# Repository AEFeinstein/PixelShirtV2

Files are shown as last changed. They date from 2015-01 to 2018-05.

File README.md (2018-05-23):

View this project on [CADLAB.io](https://cadlab.io/project/1073). 

# PixelShirtV2
PixelShirtV2 is an Arduino based collection of video games running on a matrix of WS2812b LEDs and controlled by [ATmega328p based wireless controllers](https://github.com/AEFeinstein/WirelessController). It's meant to be mounted on a shirt, but can be put anywhere.

## The Firmware

The firmware can be compiled two different ways. If one uses the makefile, it compiles as a Linux terminal application that uses the keyboard as input and draws to the terminal using ncurses. This is used for debugging. If one loads it into the Arduino IDE, it compiles as an Arduino executable that uses NRF24L01+ controllers as input and draws to a matrix of WS2812B LEDs.

Each game is a subclass of ArduinoGame. This allows the main function to keep an array of ArduinoGame pointers, and swap between them at runtime. The virtual functions each game must implement are:
* `void UpdatePhysics(void)` - This is called on an IRQ_HZ clock, currently 32Hz. Game state should be updated here.
* `void ProcessInput(int32_t p1, int32_t p2)` - This is called every time there is new player input, which may be more or less often than 32Hz. Each 32 bit parameter contains bitpacked analog joystick and digital button state.
* `void ResetGame(uint8_t isInit, uint8_t whoWon)` - This is called during initialization (noted by isInit). It should reset the game to a known state. It is usually called at the end of each round of a game with which player won (noted by whoWon), though that is game-specific.

The firmware uses the [Adafruit Neopixel Library](https://github.com/adafruit/Adafruit_NeoPixel) to drive the WS2812B LEDs.

The firmware uses the [nrf24L01+ Radio Library](https://github.com/kehribar/nrf24L01_plus) to talk to the controllers.

The current game roster is
* Pong - Move your paddle and don't let the ball get past you.
* Team Tetris - Like regular Tetris, but one player slides the piece while the other rotates. Each time a new piece spawns, the player roles swap.
* Lightcycle - Drive around, leaving a trail, and don't crash into either your or your opponent's trail. The field wraps around top-bottom and left-right.
* PixelFighter - A simple 2D fighter. Attack or block high or low and knock off your opponent's life bar,
* Space Invader - Two players shoot upwards as invaders slide to the left, drop, and reverse direction. The more invaders shot, the faster they go.

## The Hardware

The hardware consists of two parts, detailed below. 

### The Console

The first part is the pocket-sized console, which has the Arduino Micro, NRF24L01+ radio, two RJ45 jacks which break out Arduino pins, and two USB connectors which draw power from an external battery. There are two USB connectors because I used an external battery with two USB connectors which could each source 1A. Not that I ever turned the display on to max brightness, but 2A never hurt anyone...

Screenshots of the PCB layout, the top view is on the left and the bottom view is on the right:
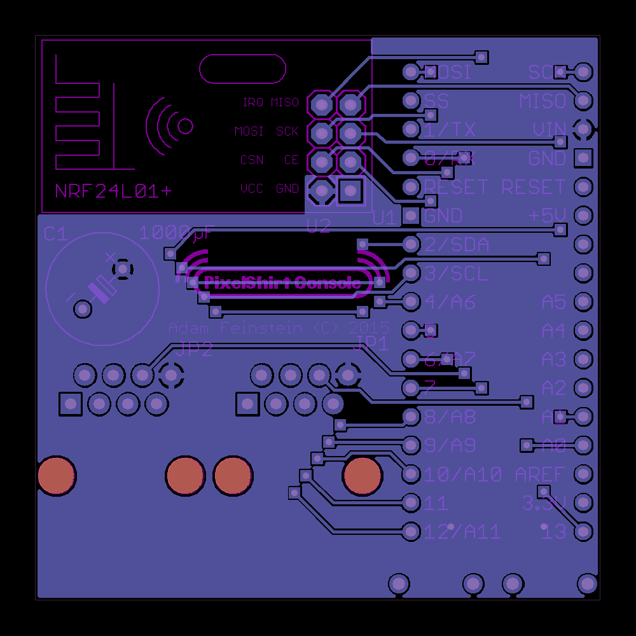
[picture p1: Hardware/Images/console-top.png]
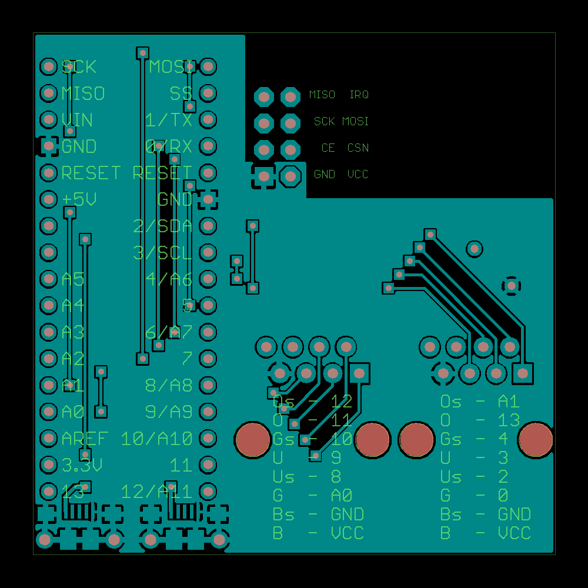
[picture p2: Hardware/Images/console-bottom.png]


This is what it looks like all soldered together:
<br>

### The Display

The second part is the chest-sized display, which has 256 WS2812B LEDs and an RJ45 connector to connect to the console for power and data. This is a one layer board, though it uses four 0-ohm resistors to jump over traces.

Screenshot of the PCB layout:
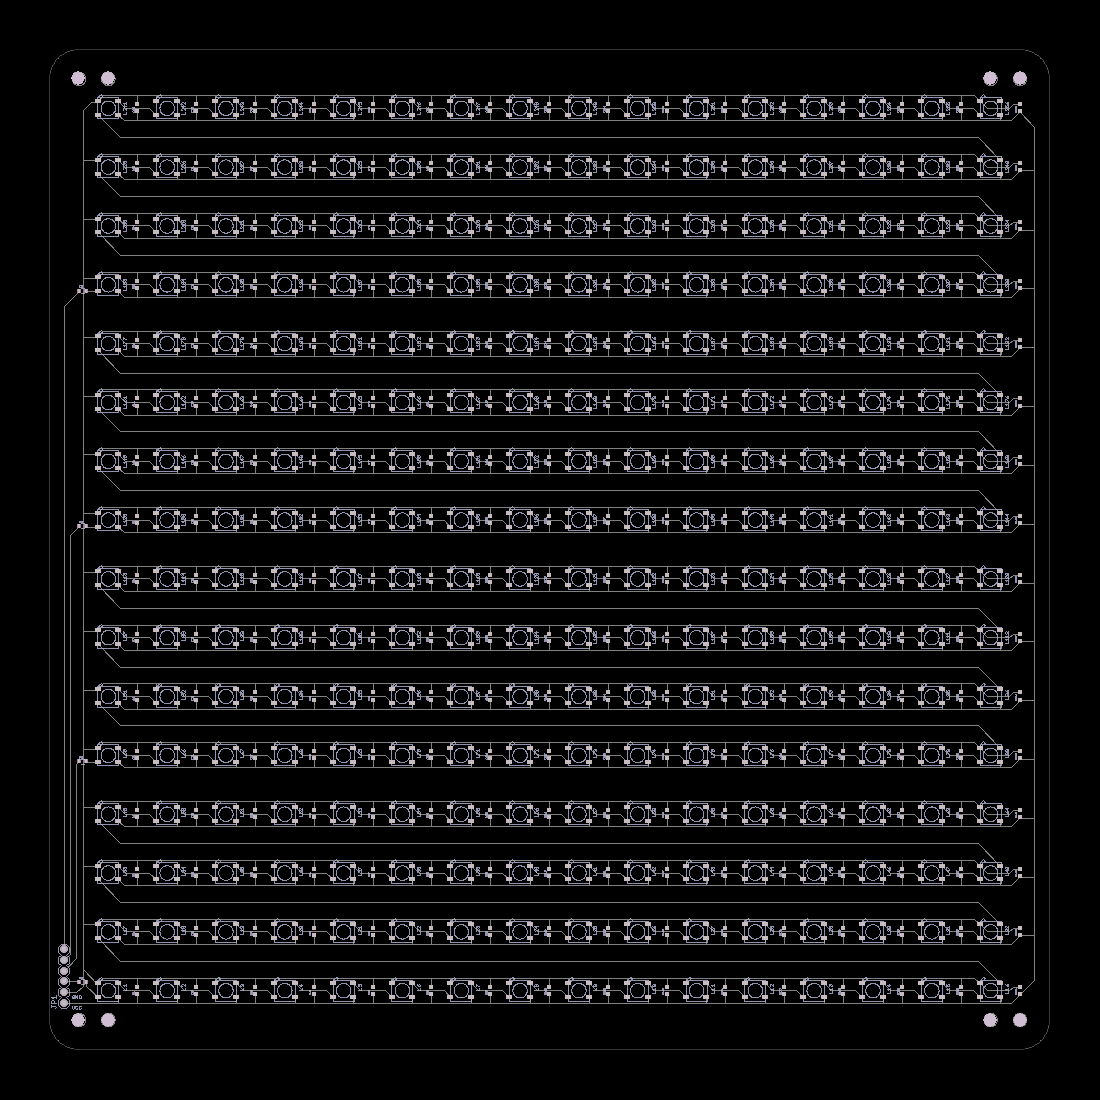
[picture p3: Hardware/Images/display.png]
<br>

This is what it looks like all soldered together. Not pictured, RJ45 connector at the end of the cable:
<br>

## The Final Product
Here's me at Magfest 14 wearing the display mounted underneath a shirt and holding two controllers. The PixelShirtV2 is playing the PixelFighter game.
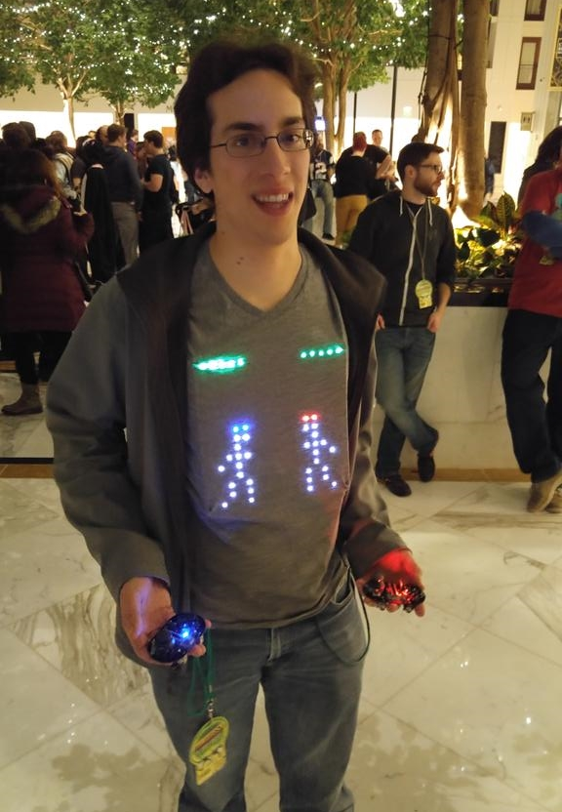
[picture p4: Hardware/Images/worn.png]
<br>

# Earlier Versions

## Version 1
The first version of the PixelShirt used blue LEDs poked through a t-shirt. The cathodes were soldered together in rows, a layer of insulating fabric was layered, then the anodes were soldered in columns. The 32 rows and columns were controlled by four daisy chained 8-bit shift registers and the display would refresh one row at a time, kind of like a CRT TV.
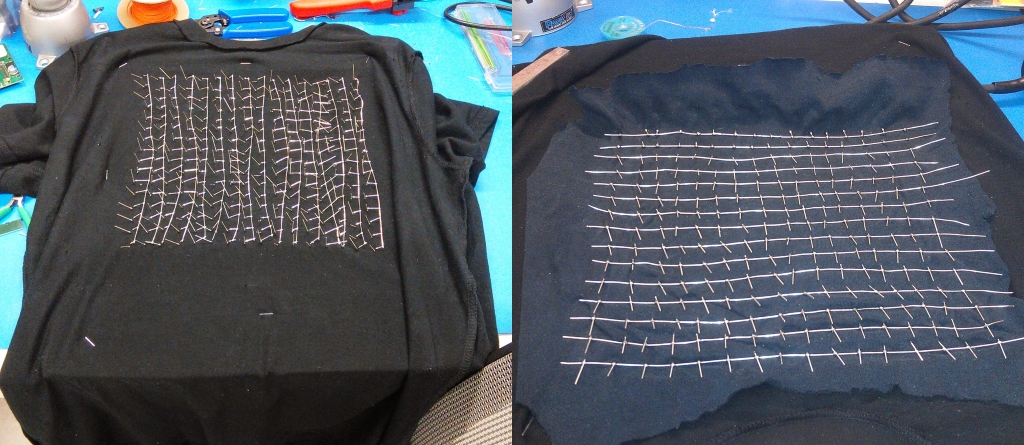
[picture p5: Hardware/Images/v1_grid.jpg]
<br>

The upside to this design was that the LED grid was flexible and comfortable. The downside was that it wasn't mechanically strong (a few solder joints broke), the grid wasn't very regular (I'm not great with fabrics), and it just generally didn't look good. The controllers are [SparkFun Joystick Shield Kits](https://www.sparkfun.com/products/9760). 
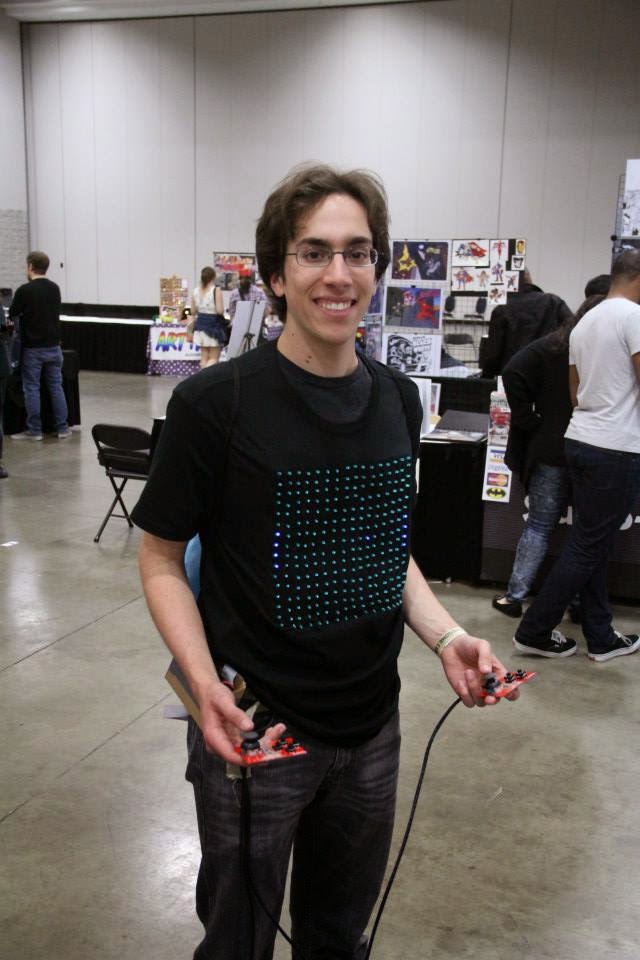
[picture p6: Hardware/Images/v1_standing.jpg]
<br>

But people seemed to get a kick out of it, so I iterated on the design. I wore it first at Magfest 12, but I think this picture is from AwesomeCon. At the time it only had Pong, Lightcycle, and Tetris.
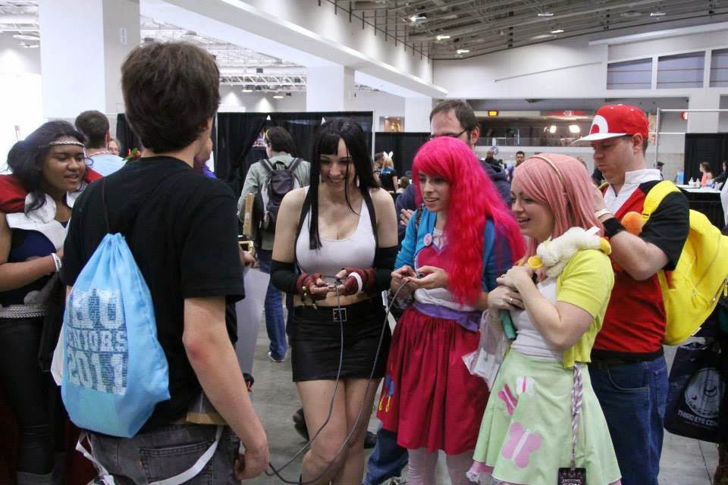
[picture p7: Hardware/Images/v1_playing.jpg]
<br>

## Version 2.0
The next year I swapped out the display for the giant PCB with RGB LEDs. Pros: colors! mechanical strength! no undershirt required! Cons: less flexible. I kept the same Sparkfun controllers. I wore this one at Magfest 13. With the advent of color, I added Space Invader.
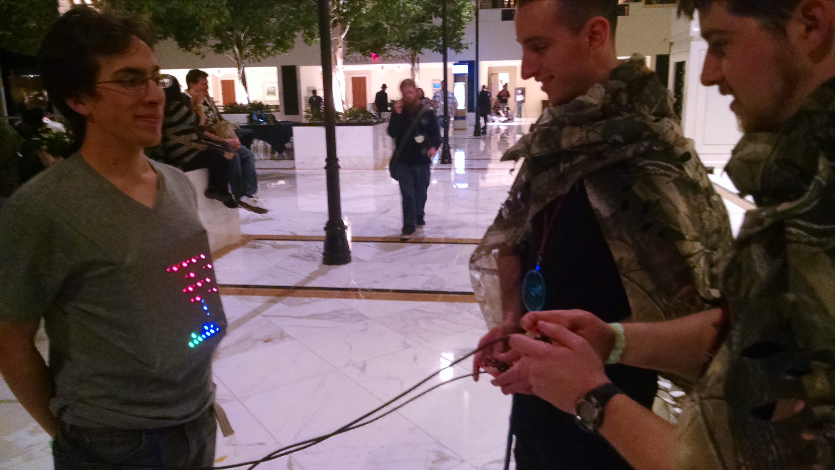
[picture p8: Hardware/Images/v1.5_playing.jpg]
<br>

## Version 2.1
For Magfest 14, I got over my fear of non-tethered controllers and made [wireless ones](https://github.com/AEFeinstein/WirelessController), which are mentioned above. They worked great and I didn't lose either one, but I did accidentally short their batteries a little when carelessly throwing them in a pocket. They got warm, but no harm no foul.

## Version 2.2
Magfest 15 only had software updates. I added the Fighter and Super Square games. There were no changes for Magfest 16, and I ended up not wearing it at all :(

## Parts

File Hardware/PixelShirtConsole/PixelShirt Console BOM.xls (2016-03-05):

Cost | Quantity | Description | PCB Reference | Part Number | Link
$24.95 | 1 | Arduino Micro | U1 |  | http://store-usa.arduino.cc/products/a000053
$2.90 | 1 | NRF24L01+MODULE | U2 | 1597-1352-ND | https://www.digikey.com/product-detail/en/seeed-technology-ltd/113990011/1597-1352-ND/5488251
$0.57 | 2 | CONN MOD JACK 8P8C R/A UNSHLD | JP1, JP2 | 609-1046-ND | https://www.digikey.com/product-detail/en/amphenol-fci/54602-908LF/609-1046-ND/1001360
$0.46 | 2 | USB micro B Receptacle, Surface Mount, Right Angle, Horizontal | JP3, JP4 | 609-4616-1-ND | https://www.digikey.com/product-detail/en/amphenol-fci/10118193-0001LF/609-4616-1-ND/2785380
$0.40 | 1 | CAP ALUM 1000UF 20% 10V RADIAL | C1 | 493-10963-1-ND | https://www.digikey.com/product-detail/en/nichicon/UFW1A102MPD1TD/493-10963-1-ND/4317887
$2.00 | 1 | PixelShirtV2 Console PCB |  |  | https://github.com/AEFeinstein/PixelShirtV2/tree/master/Hardware/PixelShirtConsole
$30.31

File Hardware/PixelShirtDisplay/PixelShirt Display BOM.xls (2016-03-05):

Cost | Quantity | Description | PCB Reference | Part Number | Link
$0.01 | 256 | CAP CER 0.1UF 16V X7R 0603 | C1-C256 | 490-1532-1-ND | https://www.digikey.com/product-detail/en/murata-electronics-north-america/GRM188R71C104KA01D/490-1532-1-ND/587771
$4.05 | 26 | LED RGB WS2812B W/DVR 4SMD 10PK | L1-L256 | 1528-1104-ND | https://www.digikey.com/product-detail/en/adafruit-industries-llc/1655/1528-1104-ND/5154679
$0.09 | 4 | RES SMD 0.0OHM JUMPER 1/10W 0603 | R2-R5 | 311-0.0HRCT-ND | https://www.digikey.com/product-detail/en/yageo/RC0603FR-070RL/311-0.0HRCT-ND/4340584
$0.26 | 1 | 2.54MM PITCH 06 POS SIL HORIZ | JP1 | 952-2372-ND | https://www.digikey.com/product-detail/en/harwin-inc/M20-9710646/952-2372-ND/3724334
$2.19 | 1 | CABLE RJ45 CAT5E W/BOOT 3' BLK |  | AE10480-ND | https://www.digikey.com/product-detail/en/assmann-wsw-components/DK-1511-003%2FBL/AE10480-ND/2268272
$10.00 | 1 | PixelShirt Display PCB |  |  | https://github.com/AEFeinstein/PixelShirtV2/tree/master/Hardware/PixelShirtDisplay
$109.91
 |  | Note: It's cheaper to get the 256 WS2812Bs on ebay

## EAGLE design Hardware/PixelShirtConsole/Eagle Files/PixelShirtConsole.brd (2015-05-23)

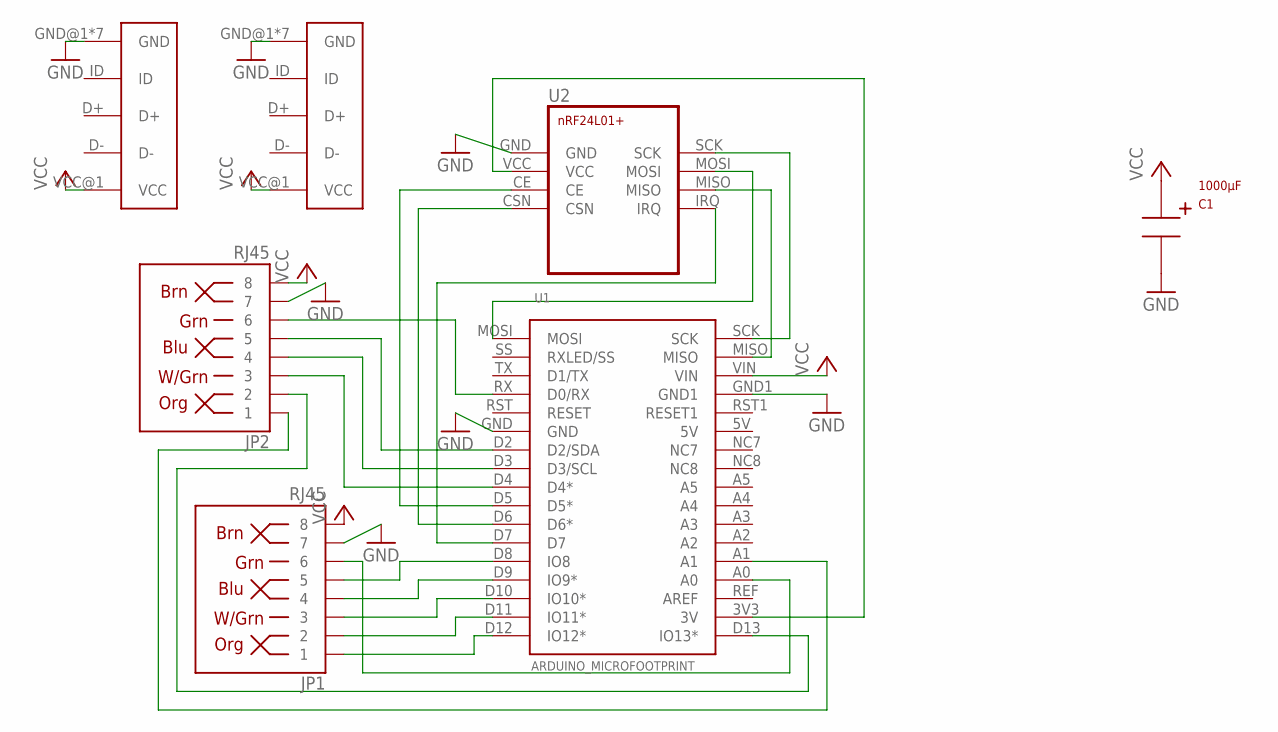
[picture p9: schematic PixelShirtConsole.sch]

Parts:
C1: 1000µF; CAP-CUSTOM
JP1, JP2: RJ45; RJ45-8
JP3, JP4: USB-MICRO-B
U1: ARDUINO_MICROFOOTPRINT; ARDUINO-MICRO
U2: NRF24L01+

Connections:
GND: C1.GND, JP1.7, JP2.7, JP3.GND@1 (GND), JP3.GND@2 (GND), JP3.GND@3 (GND), JP3.GND@5 (GND), JP3.GND@6 (GND), JP3.GND@7 (GND), JP3.GNF@4 (GND), JP4.GND@1 (GND), JP4.GND@2 (GND), JP4.GND@3 (GND), JP4.GND@5 (GND), JP4.GND@6 (GND), JP4.GND@7 (GND), JP4.GNF@4 (GND), U1.GND, U1.GND1, U2.GND
unnamed: U1.MISO, U2.MISO
unnamed: U1.SCK, U2.SCK
unnamed: U1.D6 (D6*), U2.CSN
unnamed: U1.D5 (D5*), U2.CE
unnamed: U1.MOSI, U2.MOSI
unnamed: U1.D7, U2.IRQ
unnamed: JP1.2, U1.D11 (IO11*)
unnamed: JP1.3, U1.D10 (IO10*)
unnamed: JP1.4, U1.D9 (IO9*)
unnamed: JP1.1, U1.D12 (IO12*)
unnamed: JP1.6, U1.A0
unnamed: JP1.5, U1.D8 (IO8)
unnamed: JP2.5, U1.D2 (D2/SDA)
unnamed: JP2.4, U1.D3 (D3/SCL)
unnamed: JP2.3, U1.D4 (D4*)
unnamed: JP2.6, U1.RX (D0/RX)
unnamed: JP2.1, U1.A1
unnamed: JP2.2, U1.D13 (IO13*)
unnamed: U1.3V3 (3V), U2.VCC
VCC: C1.VCC, JP1.8, JP2.8, JP3.VCC@1 (VCC), JP4.VCC@1 (VCC), U1.VIN

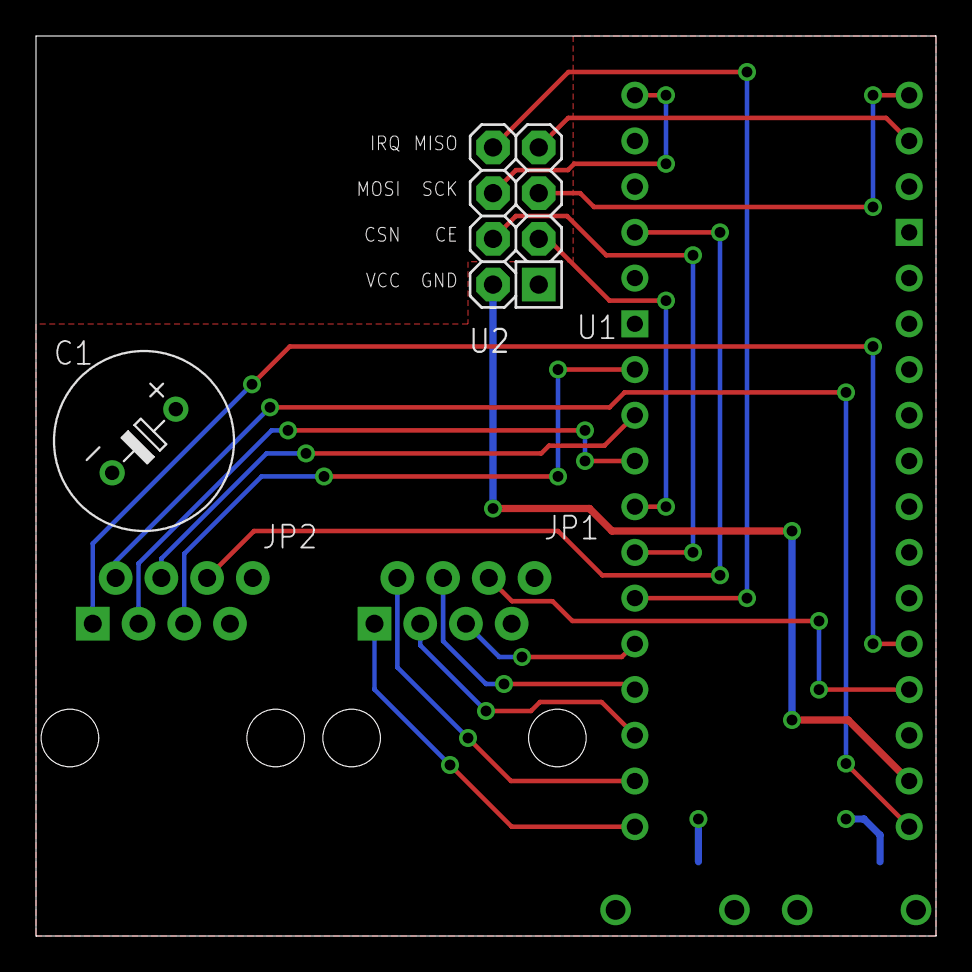
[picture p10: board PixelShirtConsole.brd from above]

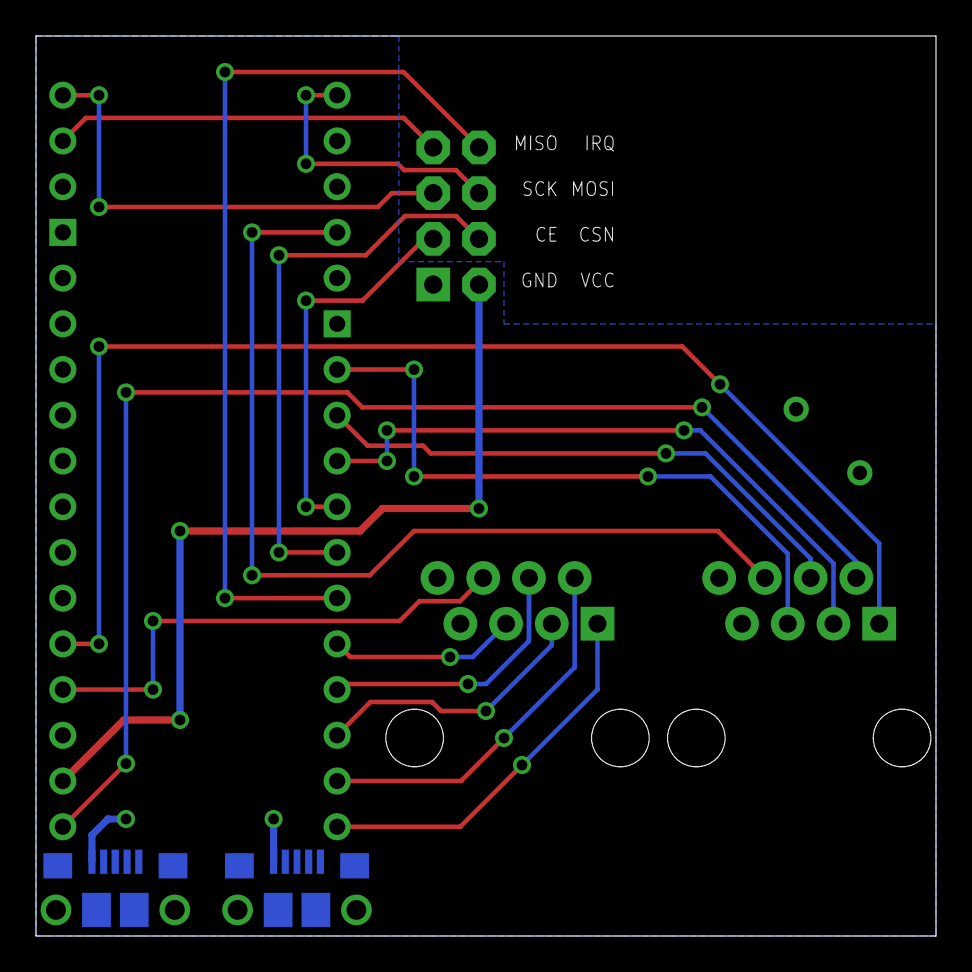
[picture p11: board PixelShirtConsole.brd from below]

Board: 2 copper layers, 50.0 x 50.0 mm, 7 parts (2 on the bottom side), 21 nets.

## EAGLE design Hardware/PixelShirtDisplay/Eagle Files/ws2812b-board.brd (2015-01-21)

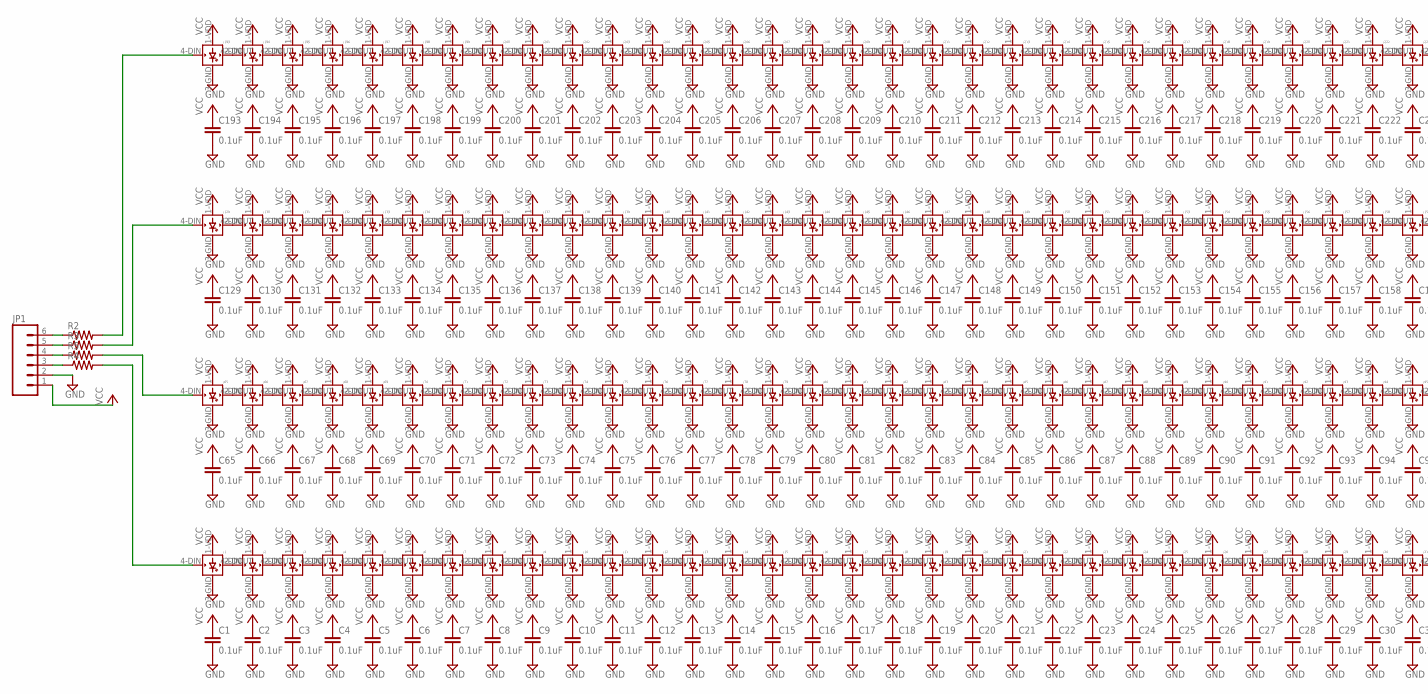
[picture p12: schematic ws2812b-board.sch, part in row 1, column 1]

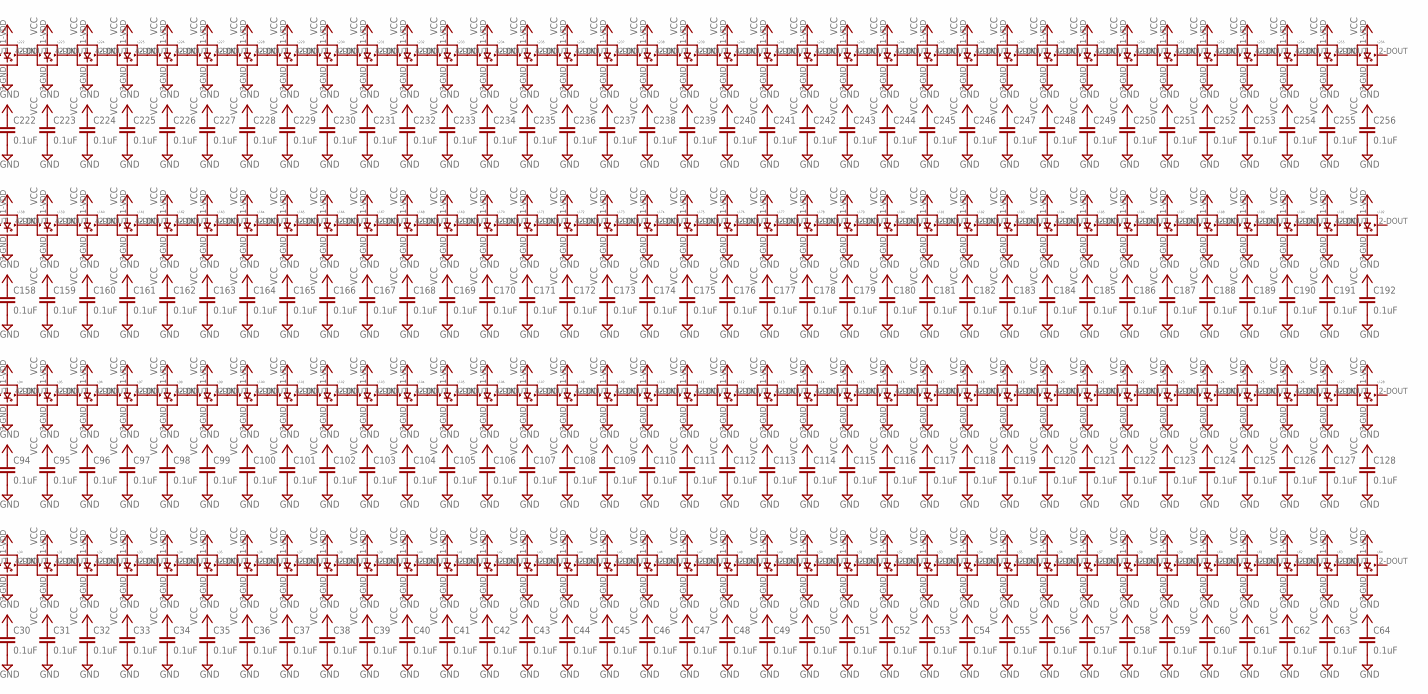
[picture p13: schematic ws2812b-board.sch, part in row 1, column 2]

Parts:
C1, C2, C3, C4, C5, C6, C7, C8, C9, C10, C11, C12, C13, C14, C15, C16, C17, C18, C19, C20, C21, C22, C23, C24, C25, C26, C27, C28, C29, C30, C31, C32, C33, C34, C35, C36, C37, C38, C39, C40, C41, C42, C43, C44, C45, C46, C47, C48, C49, C50, C51, C52, C53, C54, C55, C56, C57, C58, C59, C60, C61, C62, C63, C64, C65, C66, C67, C68, C69, C70, C71, C72, C73, C74, C75, C76, C77, C78, C79, C80, C81, C82, C83, C84, C85, C86, C87, C88, C89, C90, C91, C92, C93, C94, C95, C96, C97, C98, C99, C100, C101, C102, C103, C104, C105, C106, C107, C108, C109, C110, C111, C112, C113, C114, C115, C116, C117, C118, C119, C120, C121, C122, C123, C124, C125, C126, C127, C128, C129, C130, C131, C132, C133, C134, C135, C136, C137, C138, C139, C140, C141, C142, C143, C144, C145, C146, C147, C148, C149, C150, C151, C152, C153, C154, C155, C156, C157, C158, C159, C160, C161, C162, C163, C164, C165, C166, C167, C168, C169, C170, C171, C172, C173, C174, C175, C176, C177, C178, C179, C180, C181, C182, C183, C184, C185, C186, C187, C188, C189, C190, C191, C192, C193, C194, C195, C196, C197, C198, C199, C200, C201, C202, C203, C204, C205, C206, C207, C208, C209, C210, C211, C212, C213, C214, C215, C216, C217, C218, C219, C220, C221, C222, C223, C224, C225, C226, C227, C228, C229, C230, C231, C232, C233, C234, C235, C236, C237, C238, C239, C240, C241, C242, C243, C244, C245, C246, C247, C248, C249, C250, C251, C252, C253, C254, C255, C256: 0.1uF; 0603-CAP
JP1: M06SIP; 1X06
L1, L2, L3, L4, L5, L6, L7, L8, L9, L10, L11, L12, L13, L14, L15, L16, L17, L18, L19, L20, L21, L22, L23, L24, L25, L26, L27, L28, L29, L30, L31, L32, L33, L34, L35, L36, L37, L38, L39, L40, L41, L42, L43, L44, L45, L46, L47, L48, L49, L50, L51, L52, L53, L54, L55, L56, L57, L58, L59, L60, L61, L62, L63, L64, L65, L66, L67, L68, L69, L70, L71, L72, L73, L74, L75, L76, L77, L78, L79, L80, L81, L82, L83, L84, L85, L86, L87, L88, L89, L90, L91, L92, L93, L94, L95, L96, L97, L98, L99, L100, L101, L102, L103, L104, L105, L106, L107, L108, L109, L110, L111, L112, L113, L114, L115, L116, L117, L118, L119, L120, L121, L122, L123, L124, L125, L126, L127, L128, L129, L130, L131, L132, L133, L134, L135, L136, L137, L138, L139, L140, L141, L142, L143, L144, L145, L146, L147, L148, L149, L150, L151, L152, L153, L154, L155, L156, L157, L158, L159, L160, L161, L162, L163, L164, L165, L166, L167, L168, L169, L170, L171, L172, L173, L174, L175, L176, L177, L178, L179, L180, L181, L182, L183, L184, L185, L186, L187, L188, L189, L190, L191, L192, L193, L194, L195, L196, L197, L198, L199, L200, L201, L202, L203, L204, L205, L206, L207, L208, L209, L210, L211, L212, L213, L214, L215, L216, L217, L218, L219, L220, L221, L222, L223, L224, L225, L226, L227, L228, L229, L230, L231, L232, L233, L234, L235, L236, L237, L238, L239, L240, L241, L242, L243, L244, L245, L246, L247, L248, L249, L250, L251, L252, L253, L254, L255, L256: WS2812B
R2, R3, R4, R5: RESISTOR0805-RES; 0805

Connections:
GND: C1.2, C2.2, C3.2, C4.2, C5.2, C6.2, C7.2, C8.2, C9.2, C10.2, C11.2, C12.2, C13.2, C14.2, C15.2, C16.2, C17.2, C18.2, C19.2, C20.2, C21.2, C22.2, C23.2, C24.2, C25.2, C26.2, C27.2, C28.2, C29.2, C30.2, C31.2, C32.2, C33.2, C34.2, C35.2, C36.2, C37.2, C38.2, C39.2, C40.2, C41.2, C42.2, C43.2, C44.2, C45.2, C46.2, C47.2, C48.2, C49.2, C50.2, C51.2, C52.2, C53.2, C54.2, C55.2, C56.2, C57.2, C58.2, C59.2, C60.2, C61.2, C62.2, C63.2, C64.2, C65.2, C66.2, C67.2, C68.2, C69.2, C70.2, C71.2, C72.2, C73.2, C74.2, C75.2, C76.2, C77.2, C78.2, C79.2, C80.2, C81.2, C82.2, C83.2, C84.2, C85.2, C86.2, C87.2, C88.2, C89.2, C90.2, C91.2, C92.2, C93.2, C94.2, C95.2, C96.2, C97.2, C98.2, C99.2, C100.2, C101.2, C102.2, C103.2, C104.2, C105.2, C106.2, C107.2, C108.2, C109.2, C110.2, C111.2, C112.2, C113.2, C114.2, C115.2, C116.2, C117.2, C118.2, C119.2, C120.2, C121.2, C122.2, C123.2, C124.2, C125.2, C126.2, C127.2, C128.2, C129.2, C130.2, C131.2, C132.2, C133.2, C134.2, C135.2, C136.2, C137.2, C138.2, C139.2, C140.2, C141.2, C142.2, C143.2, C144.2, C145.2, C146.2, C147.2, C148.2, C149.2, C150.2, C151.2, C152.2, C153.2, C154.2, C155.2, C156.2, C157.2, C158.2, C159.2, C160.2, C161.2, C162.2, C163.2, C164.2, C165.2, C166.2, C167.2, C168.2, C169.2, C170.2, C171.2, C172.2, C173.2, C174.2, C175.2, C176.2, C177.2, C178.2, C179.2, C180.2, C181.2, C182.2, C183.2, C184.2, C185.2, C186.2, C187.2, C188.2, C189.2, C190.2, C191.2, C192.2, C193.2, C194.2, C195.2, C196.2, C197.2, C198.2, C199.2, C200.2, C201.2, C202.2, C203.2, C204.2, C205.2, C206.2, C207.2, C208.2, C209.2, C210.2, C211.2, C212.2, C213.2, C214.2, C215.2, C216.2, C217.2, C218.2, C219.2, C220.2, C221.2, C222.2, C223.2, C224.2, C225.2, C226.2, C227.2, C228.2, C229.2, C230.2, C231.2, C232.2, C233.2, C234.2, C235.2, C236.2, C237.2, C238.2, C239.2, C240.2, C241.2, C242.2, C243.2, C244.2, C245.2, C246.2, C247.2, C248.2, C249.2, C250.2, C251.2, C252.2, C253.2, C254.2, C255.2, C256.2, JP1.2, L1.3-GND (GND), L2.3-GND (GND), L3.3-GND (GND), L4.3-GND (GND), L5.3-GND (GND), L6.3-GND (GND), L7.3-GND (GND), L8.3-GND (GND), L9.3-GND (GND), L10.3-GND (GND), L11.3-GND (GND), L12.3-GND (GND), L13.3-GND (GND), L14.3-GND (GND), L15.3-GND (GND), L16.3-GND (GND), L17.3-GND (GND), L18.3-GND (GND), L19.3-GND (GND), L20.3-GND (GND), L21.3-GND (GND), L22.3-GND (GND), L23.3-GND (GND), L24.3-GND (GND), L25.3-GND (GND), L26.3-GND (GND), L27.3-GND (GND), L28.3-GND (GND), L29.3-GND (GND), L30.3-GND (GND), L31.3-GND (GND), L32.3-GND (GND), L33.3-GND (GND), L34.3-GND (GND), L35.3-GND (GND), L36.3-GND (GND), L37.3-GND (GND), L38.3-GND (GND), L39.3-GND (GND), L40.3-GND (GND), L41.3-GND (GND), L42.3-GND (GND), L43.3-GND (GND), L44.3-GND (GND), L45.3-GND (GND), L46.3-GND (GND), L47.3-GND (GND), L48.3-GND (GND), L49.3-GND (GND), L50.3-GND (GND), L51.3-GND (GND), L52.3-GND (GND), L53.3-GND (GND), L54.3-GND (GND), L55.3-GND (GND), L56.3-GND (GND), L57.3-GND (GND), L58.3-GND (GND), L59.3-GND (GND), L60.3-GND (GND), L61.3-GND (GND), L62.3-GND (GND), L63.3-GND (GND), L64.3-GND (GND), L65.3-GND (GND), L66.3-GND (GND), L67.3-GND (GND), L68.3-GND (GND), L69.3-GND (GND), L70.3-GND (GND), L71.3-GND (GND), L72.3-GND (GND), L73.3-GND (GND), L74.3-GND (GND), L75.3-GND (GND), L76.3-GND (GND), L77.3-GND (GND), L78.3-GND (GND), L79.3-GND (GND), L80.3-GND (GND), L81.3-GND (GND), L82.3-GND (GND), L83.3-GND (GND), L84.3-GND (GND), L85.3-GND (GND), L86.3-GND (GND), L87.3-GND (GND), L88.3-GND (GND), L89.3-GND (GND), L90.3-GND (GND), L91.3-GND (GND), L92.3-GND (GND), L93.3-GND (GND), L94.3-GND (GND), L95.3-GND (GND), L96.3-GND (GND), L97.3-GND (GND), L98.3-GND (GND), L99.3-GND (GND), L100.3-GND (GND), L101.3-GND (GND), L102.3-GND (GND), L103.3-GND (GND), L104.3-GND (GND), L105.3-GND (GND), L106.3-GND (GND), L107.3-GND (GND), L108.3-GND (GND), L109.3-GND (GND), L110.3-GND (GND), L111.3-GND (GND), L112.3-GND (GND), L113.3-GND (GND), L114.3-GND (GND), L115.3-GND (GND), L116.3-GND (GND), L117.3-GND (GND), L118.3-GND (GND), L119.3-GND (GND), L120.3-GND (GND), L121.3-GND (GND), L122.3-GND (GND), L123.3-GND (GND), L124.3-GND (GND), L125.3-GND (GND), L126.3-GND (GND), L127.3-GND (GND), L128.3-GND (GND), L129.3-GND (GND), L130.3-GND (GND), L131.3-GND (GND), L132.3-GND (GND), L133.3-GND (GND), L134.3-GND (GND), L135.3-GND (GND), L136.3-GND (GND), L137.3-GND (GND), L138.3-GND (GND), L139.3-GND (GND), L140.3-GND (GND), L141.3-GND (GND), L142.3-GND (GND), L143.3-GND (GND), L144.3-GND (GND), L145.3-GND (GND), L146.3-GND (GND), L147.3-GND (GND), L148.3-GND (GND), L149.3-GND (GND), L150.3-GND (GND), L151.3-GND (GND), L152.3-GND (GND), L153.3-GND (GND), L154.3-GND (GND), L155.3-GND (GND), L156.3-GND (GND), L157.3-GND (GND), L158.3-GND (GND), L159.3-GND (GND), L160.3-GND (GND), L161.3-GND (GND), L162.3-GND (GND), L163.3-GND (GND), L164.3-GND (GND), L165.3-GND (GND), L166.3-GND (GND), L167.3-GND (GND), L168.3-GND (GND), L169.3-GND (GND), L170.3-GND (GND), L171.3-GND (GND), L172.3-GND (GND), L173.3-GND (GND), L174.3-GND (GND), L175.3-GND (GND), L176.3-GND (GND), L177.3-GND (GND), L178.3-GND (GND), L179.3-GND (GND), L180.3-GND (GND), L181.3-GND (GND), L182.3-GND (GND), L183.3-GND (GND), L184.3-GND (GND), L185.3-GND (GND), L186.3-GND (GND), L187.3-GND (GND), L188.3-GND (GND), L189.3-GND (GND), L190.3-GND (GND), L191.3-GND (GND), L192.3-GND (GND), L193.3-GND (GND), L194.3-GND (GND), L195.3-GND (GND), L196.3-GND (GND), L197.3-GND (GND), L198.3-GND (GND), L199.3-GND (GND), L200.3-GND (GND), L201.3-GND (GND), L202.3-GND (GND), L203.3-GND (GND), L204.3-GND (GND), L205.3-GND (GND), L206.3-GND (GND), L207.3-GND (GND), L208.3-GND (GND), L209.3-GND (GND), L210.3-GND (GND), L211.3-GND (GND), L212.3-GND (GND), L213.3-GND (GND), L214.3-GND (GND), L215.3-GND (GND), L216.3-GND (GND), L217.3-GND (GND), L218.3-GND (GND), L219.3-GND (GND), L220.3-GND (GND), L221.3-GND (GND), L222.3-GND (GND), L223.3-GND (GND), L224.3-GND (GND), L225.3-GND (GND), L226.3-GND (GND), L227.3-GND (GND), L228.3-GND (GND), L229.3-GND (GND), L230.3-GND (GND), L231.3-GND (GND), L232.3-GND (GND), L233.3-GND (GND), L234.3-GND (GND), L235.3-GND (GND), L236.3-GND (GND), L237.3-GND (GND), L238.3-GND (GND), L239.3-GND (GND), L240.3-GND (GND), L241.3-GND (GND), L242.3-GND (GND), L243.3-GND (GND), L244.3-GND (GND), L245.3-GND (GND), L246.3-GND (GND), L247.3-GND (GND), L248.3-GND (GND), L249.3-GND (GND), L250.3-GND (GND), L251.3-GND (GND), L252.3-GND (GND), L253.3-GND (GND), L254.3-GND (GND), L255.3-GND (GND), L256.3-GND (GND)
unnamed: L1.2-DOUT (DOUT), L2.4-DIN (DIN)
unnamed: L2.2-DOUT (DOUT), L3.4-DIN (DIN)
unnamed: L3.2-DOUT (DOUT), L4.4-DIN (DIN)
unnamed: L4.2-DOUT (DOUT), L5.4-DIN (DIN)
unnamed: L5.2-DOUT (DOUT), L6.4-DIN (DIN)
unnamed: L6.2-DOUT (DOUT), L7.4-DIN (DIN)
unnamed: L7.2-DOUT (DOUT), L8.4-DIN (DIN)
unnamed: L8.2-DOUT (DOUT), L9.4-DIN (DIN)
unnamed: L9.2-DOUT (DOUT), L10.4-DIN (DIN)
unnamed: L10.2-DOUT (DOUT), L11.4-DIN (DIN)
unnamed: L11.2-DOUT (DOUT), L12.4-DIN (DIN)
unnamed: L12.2-DOUT (DOUT), L13.4-DIN (DIN)
unnamed: L13.2-DOUT (DOUT), L14.4-DIN (DIN)
unnamed: L14.2-DOUT (DOUT), L15.4-DIN (DIN)
unnamed: L15.2-DOUT (DOUT), L16.4-DIN (DIN)
unnamed: L16.2-DOUT (DOUT), L17.4-DIN (DIN)
unnamed: L17.2-DOUT (DOUT), L18.4-DIN (DIN)
unnamed: L18.2-DOUT (DOUT), L19.4-DIN (DIN)
unnamed: L19.2-DOUT (DOUT), L20.4-DIN (DIN)
unnamed: L20.2-DOUT (DOUT), L21.4-DIN (DIN)
unnamed: L21.2-DOUT (DOUT), L22.4-DIN (DIN)
unnamed: L22.2-DOUT (DOUT), L23.4-DIN (DIN)
unnamed: L23.2-DOUT (DOUT), L24.4-DIN (DIN)
unnamed: L24.2-DOUT (DOUT), L25.4-DIN (DIN)
unnamed: L25.2-DOUT (DOUT), L26.4-DIN (DIN)
unnamed: L26.2-DOUT (DOUT), L27.4-DIN (DIN)
unnamed: L27.2-DOUT (DOUT), L28.4-DIN (DIN)
unnamed: L28.2-DOUT (DOUT), L29.4-DIN (DIN)
unnamed: L29.2-DOUT (DOUT), L30.4-DIN (DIN)
unnamed: L30.2-DOUT (DOUT), L31.4-DIN (DIN)
unnamed: L31.2-DOUT (DOUT), L32.4-DIN (DIN)
unnamed: L32.2-DOUT (DOUT), L33.4-DIN (DIN)
unnamed: L33.2-DOUT (DOUT), L34.4-DIN (DIN)
unnamed: L34.2-DOUT (DOUT), L35.4-DIN (DIN)
unnamed: L35.2-DOUT (DOUT), L36.4-DIN (DIN)
unnamed: L36.2-DOUT (DOUT), L37.4-DIN (DIN)
unnamed: L37.2-DOUT (DOUT), L38.4-DIN (DIN)
unnamed: L38.2-DOUT (DOUT), L39.4-DIN (DIN)
unnamed: L39.2-DOUT (DOUT), L40.4-DIN (DIN)
unnamed: L40.2-DOUT (DOUT), L41.4-DIN (DIN)
unnamed: L41.2-DOUT (DOUT), L42.4-DIN (DIN)
unnamed: L42.2-DOUT (DOUT), L43.4-DIN (DIN)
unnamed: L43.2-DOUT (DOUT), L44.4-DIN (DIN)
unnamed: L44.2-DOUT (DOUT), L45.4-DIN (DIN)
unnamed: L45.2-DOUT (DOUT), L46.4-DIN (DIN)
unnamed: L46.2-DOUT (DOUT), L47.4-DIN (DIN)
unnamed: L47.2-DOUT (DOUT), L48.4-DIN (DIN)
unnamed: L48.2-DOUT (DOUT), L49.4-DIN (DIN)
unnamed: L49.2-DOUT (DOUT), L50.4-DIN (DIN)
unnamed: L50.2-DOUT (DOUT), L51.4-DIN (DIN)
unnamed: L51.2-DOUT (DOUT), L52.4-DIN (DIN)
unnamed: L52.2-DOUT (DOUT), L53.4-DIN (DIN)
unnamed: L53.2-DOUT (DOUT), L54.4-DIN (DIN)
unnamed: L54.2-DOUT (DOUT), L55.4-DIN (DIN)
unnamed: L55.2-DOUT (DOUT), L56.4-DIN (DIN)
unnamed: L56.2-DOUT (DOUT), L57.4-DIN (DIN)
unnamed: L57.2-DOUT (DOUT), L58.4-DIN (DIN)
unnamed: L58.2-DOUT (DOUT), L59.4-DIN (DIN)
unnamed: L59.2-DOUT (DOUT), L60.4-DIN (DIN)
unnamed: L60.2-DOUT (DOUT), L61.4-DIN (DIN)
unnamed: L61.2-DOUT (DOUT), L62.4-DIN (DIN)
unnamed: L62.2-DOUT (DOUT), L63.4-DIN (DIN)
unnamed: L63.2-DOUT (DOUT), L64.4-DIN (DIN)
unnamed: L65.2-DOUT (DOUT), L66.4-DIN (DIN)
unnamed: L66.2-DOUT (DOUT), L67.4-DIN (DIN)
unnamed: L67.2-DOUT (DOUT), L68.4-DIN (DIN)
unnamed: L68.2-DOUT (DOUT), L69.4-DIN (DIN)
unnamed: L69.2-DOUT (DOUT), L70.4-DIN (DIN)
unnamed: L70.2-DOUT (DOUT), L71.4-DIN (DIN)
unnamed: L71.2-DOUT (DOUT), L72.4-DIN (DIN)
unnamed: L72.2-DOUT (DOUT), L73.4-DIN (DIN)
unnamed: L73.2-DOUT (DOUT), L74.4-DIN (DIN)
unnamed: L74.2-DOUT (DOUT), L75.4-DIN (DIN)
unnamed: L75.2-DOUT (DOUT), L76.4-DIN (DIN)
unnamed: L76.2-DOUT (DOUT), L77.4-DIN (DIN)
unnamed: L77.2-DOUT (DOUT), L78.4-DIN (DIN)
unnamed: L78.2-DOUT (DOUT), L79.4-DIN (DIN)
unnamed: L79.2-DOUT (DOUT), L80.4-DIN (DIN)
unnamed: L80.2-DOUT (DOUT), L81.4-DIN (DIN)
unnamed: L81.2-DOUT (DOUT), L82.4-DIN (DIN)
unnamed: L82.2-DOUT (DOUT), L83.4-DIN (DIN)
unnamed: L83.2-DOUT (DOUT), L84.4-DIN (DIN)
unnamed: L84.2-DOUT (DOUT), L85.4-DIN (DIN)
unnamed: L85.2-DOUT (DOUT), L86.4-DIN (DIN)
unnamed: L86.2-DOUT (DOUT), L87.4-DIN (DIN)
unnamed: L87.2-DOUT (DOUT), L88.4-DIN (DIN)
unnamed: L88.2-DOUT (DOUT), L89.4-DIN (DIN)
unnamed: L89.2-DOUT (DOUT), L90.4-DIN (DIN)
unnamed: L90.2-DOUT (DOUT), L91.4-DIN (DIN)
unnamed: L91.2-DOUT (DOUT), L92.4-DIN (DIN)
unnamed: L92.2-DOUT (DOUT), L93.4-DIN (DIN)
unnamed: L93.2-DOUT (DOUT), L94.4-DIN (DIN)
unnamed: L94.2-DOUT (DOUT), L95.4-DIN (DIN)
unnamed: L95.2-DOUT (DOUT), L96.4-DIN (DIN)
unnamed: L96.2-DOUT (DOUT), L97.4-DIN (DIN)
unnamed: L97.2-DOUT (DOUT), L98.4-DIN (DIN)
unnamed: L98.2-DOUT (DOUT), L99.4-DIN (DIN)
unnamed: L99.2-DOUT (DOUT), L100.4-DIN (DIN)
unnamed: L100.2-DOUT (DOUT), L101.4-DIN (DIN)
unnamed: L101.2-DOUT (DOUT), L102.4-DIN (DIN)
unnamed: L102.2-DOUT (DOUT), L103.4-DIN (DIN)
unnamed: L103.2-DOUT (DOUT), L104.4-DIN (DIN)
unnamed: L104.2-DOUT (DOUT), L105.4-DIN (DIN)
unnamed: L105.2-DOUT (DOUT), L106.4-DIN (DIN)
unnamed: L106.2-DOUT (DOUT), L107.4-DIN (DIN)
unnamed: L107.2-DOUT (DOUT), L108.4-DIN (DIN)
unnamed: L108.2-DOUT (DOUT), L109.4-DIN (DIN)
unnamed: L109.2-DOUT (DOUT), L110.4-DIN (DIN)
unnamed: L110.2-DOUT (DOUT), L111.4-DIN (DIN)
unnamed: L111.2-DOUT (DOUT), L112.4-DIN (DIN)
unnamed: L112.2-DOUT (DOUT), L113.4-DIN (DIN)
unnamed: L113.2-DOUT (DOUT), L114.4-DIN (DIN)
unnamed: L114.2-DOUT (DOUT), L115.4-DIN (DIN)
unnamed: L115.2-DOUT (DOUT), L116.4-DIN (DIN)
unnamed: L116.2-DOUT (DOUT), L117.4-DIN (DIN)
unnamed: L117.2-DOUT (DOUT), L118.4-DIN (DIN)
unnamed: L118.2-DOUT (DOUT), L119.4-DIN (DIN)
unnamed: L119.2-DOUT (DOUT), L120.4-DIN (DIN)
unnamed: L120.2-DOUT (DOUT), L121.4-DIN (DIN)
unnamed: L121.2-DOUT (DOUT), L122.4-DIN (DIN)
unnamed: L122.2-DOUT (DOUT), L123.4-DIN (DIN)
unnamed: L123.2-DOUT (DOUT), L124.4-DIN (DIN)
unnamed: L124.2-DOUT (DOUT), L125.4-DIN (DIN)
unnamed: L125.2-DOUT (DOUT), L126.4-DIN (DIN)
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

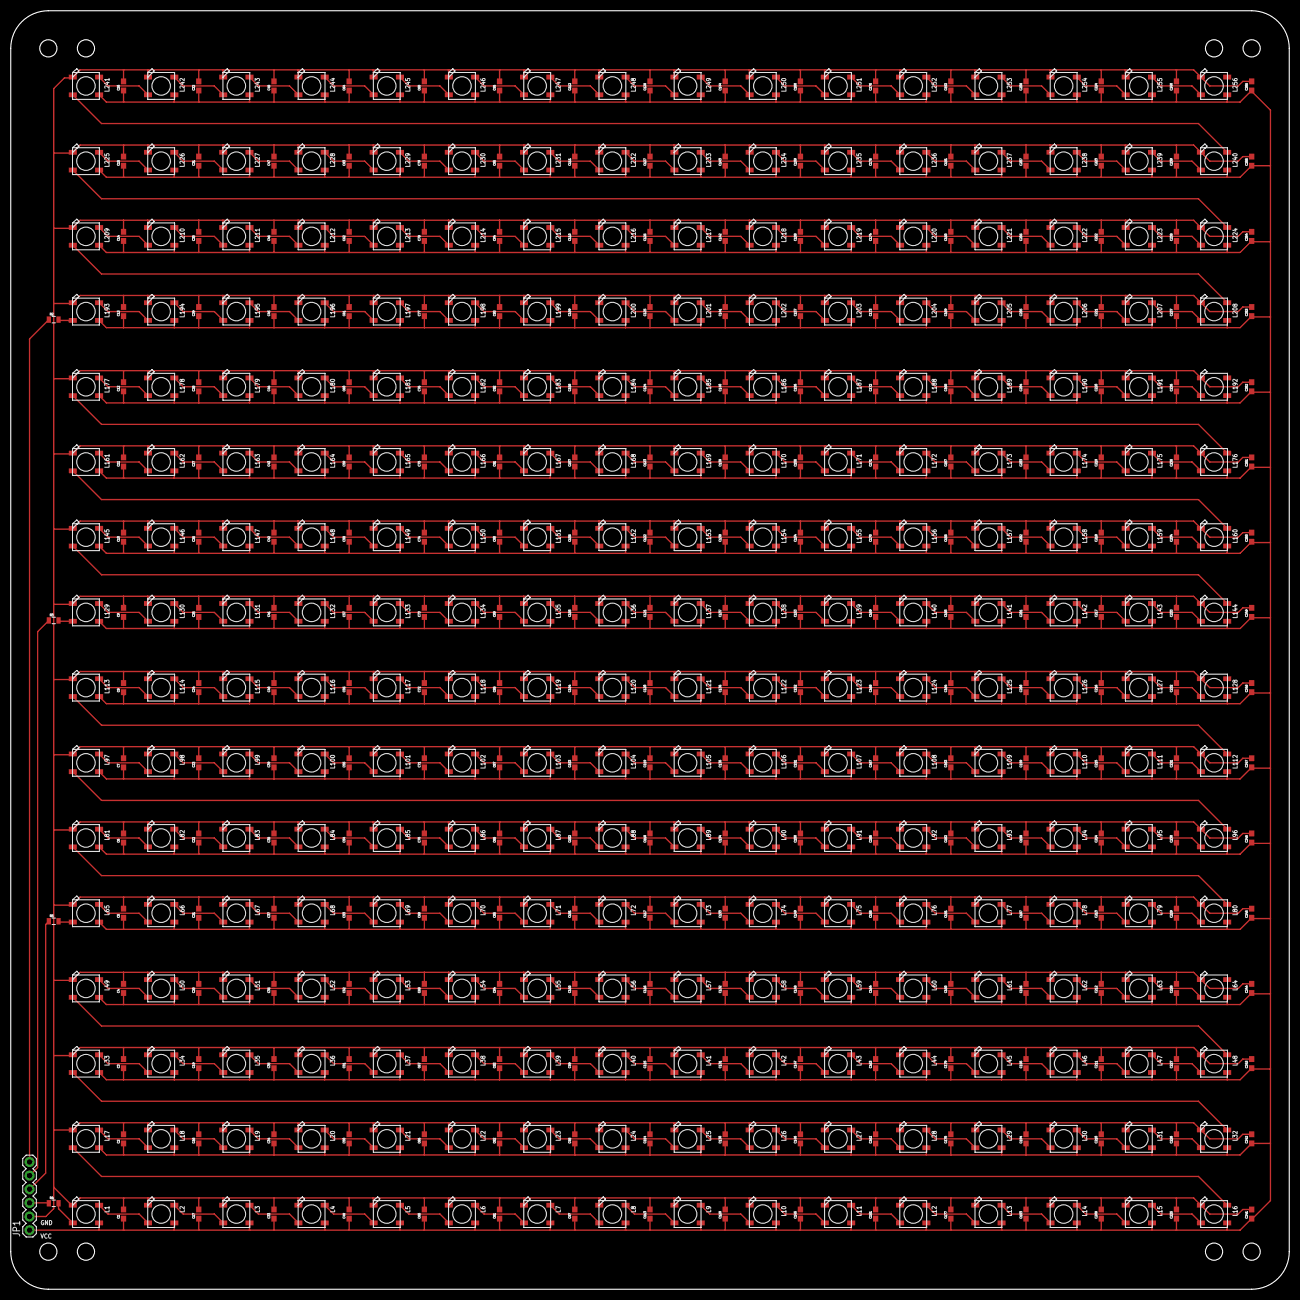
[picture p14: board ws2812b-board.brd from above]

Board: 2 copper layers, 238.0 x 238.0 mm, 517 parts (0 on the bottom side), 262 nets.

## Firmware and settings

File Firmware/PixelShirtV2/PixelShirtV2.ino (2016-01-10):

/* Copyright 2015 Adam Feinstein
 *
 * This file is part of PixelShirtV2.
 *
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
 * PixelShirtV2 is distributed in the hope that it will be useful,
 * but WITHOUT ANY WARRANTY; without even the implied warranty of
 * MERCHANTABILITY or FITNESS FOR A PARTICULAR PURPOSE.  See the
 * GNU General Public License for more details.
 * You should have received a copy of the GNU General Public License
 * along with PixelShirtV2.  If not, see <http://www.gnu.org/licenses/>.
 */

#include <stdint.h>
#include "ArduinoGame.h"

#include "Pong.h"
#include "Lightcycle.h"
#include "Tetris.h"
#include "SuperSquare.h"
#include "Shooter.h"
#include "PixelFighter.h"
#include "ScreenSaver.h"
#include "ScoreDisplay.h"

#include "PlatformSpecific.h"
#include "PixelShirtV2.h"

/* The different game IDs */
typedef enum {
  //  SUPER_SQUARE,
  PONG,
  LIGHTCYCLE,
  SHOOTER,
  TETRIS,
  FIGHTER,
  LAST_GAME
} gameType_t;

/* The current game's ID */
uint8_t gameMode;

/* A timer for game switching. It counts how long both "up" buttons are
 * pressed
 */
uint8_t gameSwitchTimer;

/* A pointer to the active game */
ArduinoGame* currentGame;

/* The collection of games */
//SuperSquare superSquare;
Pong pong;
Lightcycle lightcycle;
Shooter shooter;
Tetris tetris;
PixelFighterGame fighter;

/* To periodically call the main function in the loop */
uint32_t microsCnt = 0;
uint32_t microsLast = 0;

/* Variables to store controller state */
uint32_t p1controller;
uint32_t p2controller;

/* Prototypes */
void doEverything(void);

/**
 * The setup function. This is called once before loop() is called infinitely.
 * It sets up the hardware interfaces for driving LEDs and receiving controller
 * data. It also sets up the RNG, the initial game, and resets all state
 * variables.
 */
void setup(void)
{
  initializeHardware();

  /* Clear Variables */
  uint8_t x, y;
  for(x = 0; x < BOARD_SIZE; x++) {
    for(y = 0; y < BOARD_SIZE; y++) {
      SetPixel(x, y, EMPTY_COLOR);
    }
  }
  gameSwitchTimer = 0;

  /* Set the current game */
  gameMode = FIGHTER;
  currentGame = &fighter;
  currentGame->ResetGame(1,0);

  /* Initialize controller state */
  p1controller = 0;
  p2controller = 0;
  SET_X_AXIS(p1controller, 512);
  SET_Y_AXIS(p1controller, 512);
  SET_X_AXIS(p2controller, 512);
  SET_Y_AXIS(p2controller, 512);
}

/**
 * This function is called within an infinite loop. It calls doEverything() at
 * 32Hz and is always listening for controller input data. It also blinks
 * a heart-beat LED.
 */
void loop(void)
{
  uint32_t currentTime = getMicroseconds();

  /* Run the code at 32Hz (every 31250 microseconds)
   * Only add to the counter if it doesn't roll over
   */
  if(currentTime > microsLast) {
    microsCnt += (currentTime - microsLast);
  }
  if(microsCnt >= (1000000 / IRQ_HZ)) {
    microsCnt = 0;
    doEverything();
  }
  microsLast = currentTime;

  /* If there was new joystick data read, process it */
  if(readJoystickData(&p1controller, &p2controller)) {
    currentGame->ProcessInput(p1controller, p2controller);
    platformPostprocessInput(&p1controller, &p2controller);
  }
}

/**
 * This is called at 32Hz. It handles displaying the screen saver, switching
 * between game modes, sending controller input and update physics requests
 * to the active game, and actually pushing the pixel data out to the display.
 */
void doEverything(void)
{
  /* If both up buttons are held, maybe the game mode is being changed */
  if((GET_BUTTONS(p1controller) & UP) && (GET_BUTTONS(p2controller) & UP)) {
    gameSwitchTimer++;
  }
  else {
    gameSwitchTimer = 0;
  }

  /* If there is any input, exit the screen saver */
  if((GET_BUTTONS(p1controller) & UP) ||
      (GET_BUTTONS(p1controller) & DOWN) ||
      (GET_BUTTONS(p1controller) & LEFT) ||
      (GET_BUTTONS(p1controller) & RIGHT) ||
      ((GET_X_AXIS(p1controller)) < 512 - DEAD_ZONE ||
       512 + DEAD_ZONE < (GET_X_AXIS(p1controller))) ||
      ((GET_Y_AXIS(p1controller)) < 512 - DEAD_ZONE ||
       512 + DEAD_ZONE < (GET_Y_AXIS(p1controller))) ||
      (GET_BUTTONS(p2controller) & UP) ||
      (GET_BUTTONS(p2controller) & DOWN) ||
      (GET_BUTTONS(p2controller) & LEFT) ||
      (GET_BUTTONS(p2controller) & RIGHT) ||
      ((GET_X_AXIS(p2controller)) < 512 - DEAD_ZONE ||
       512 + DEAD_ZONE < (GET_X_AXIS(p2controller))) ||
      ((GET_Y_AXIS(p2controller)) < 512 - DEAD_ZONE ||
       512 + DEAD_ZONE < (GET_Y_AXIS(p2controller)))) {
    ExitScreensaver(currentGame);
  }

  /* Decrement the screen saver timer */
  HandleScreensaverTimer();

  if(GetScreensaverTimer() == 0) {
    DisplayScreensaver();
  }
  else {
    /* The game mode is being changed */
    if(gameSwitchTimer == IRQ_HZ * 2) {
      gameSwitchTimer = 0;
      switchGame();
    }
    else {
      /* Update the game state */
      currentGame->UpdatePhysics();
    }
  }

  /* Display the frame */
  displayPixels();
}

/**
 * Cycles through the available games.
 * Switches to the next one & resets it
 */
void switchGame(void)
{
  gameMode = (gameMode+1)%LAST_GAME;
  switch(gameMode) {
    case PONG: {
        currentGame = &pong;
        break;
      }
    case LIGHTCYCLE: {
        currentGame = &lightcycle;
        break;
      }
    case TETRIS: {
        currentGame = &tetris;
        break;
      }
    //    case SUPER_SQUARE: {
    //        currentGame = &superSquare;
    //        break;
    //      }
    case SHOOTER: {
        currentGame = &shooter;
        break;
      }
    case FIGHTER: {
        currentGame = &fighter;
        break;
      }
  }
  currentGame->ResetGame(1,0);
}

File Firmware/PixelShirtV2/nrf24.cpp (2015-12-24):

/*
* ----------------------------------------------------------------------------
* THE COFFEEWARE LICENSE (Revision 1):
* <ihsan@kehribar.me> wrote this file. As long as you retain this notice you
* can do whatever you want with this stuff. If we meet some day, and you think
* this stuff is worth it, you can buy me a coffee in return.
* -----------------------------------------------------------------------------
* This library is based on this library:
*   https://github.com/aaronds/arduino-nrf24l01
* Which is based on this library:
*   http://www.tinkerer.eu/AVRLib/nRF24L01
* -----------------------------------------------------------------------------
*/

#include <stdint.h>
#include "nRF24L01.h"
#include "nrf24.h"

#ifdef ARDUINO

#include "Arduino.h"

uint8_t payload_len;

/* init the hardware pins */
void nrf24_init(void)
{
  nrf24_setupPins();
  nrf24_ce_digitalWrite(LOW);
  nrf24_csn_digitalWrite(HIGH);
}

/* configure the module */
void nrf24_config(uint8_t channel, uint8_t pay_length)
{
  /* Use static payload length ... */
  payload_len = pay_length;

  /* Set RF channel */
  nrf24_configRegister(RF_CH,channel);

  /* Set length of incoming payload */
  nrf24_configRegister(RX_PW_P0, 0x00); /* Auto-ACK pipe ... */
  nrf24_configRegister(RX_PW_P1, payload_len); /* Data payload pipe */
  nrf24_configRegister(RX_PW_P2, 0x00); /* Pipe not used */
  nrf24_configRegister(RX_PW_P3, 0x00); /* Pipe not used */
  nrf24_configRegister(RX_PW_P4, 0x00); /* Pipe not used */
  nrf24_configRegister(RX_PW_P5, 0x00); /* Pipe not used */

  /* 1 Mbps, TX gain: 0dbm */
  nrf24_configRegister(RF_SETUP, (0<<RF_DR)|((0x03)<<RF_PWR));

  /* CRC enable, 1 byte CRC length */
  nrf24_configRegister(CONFIG,nrf24_CONFIG);

  /* Auto Acknowledgment */
  nrf24_configRegister(EN_AA,
                       (1<<ENAA_P0)|(1<<ENAA_P1)|(0<<ENAA_P2)|(0<<ENAA_P3)|(0<<ENAA_P4)|(0<<ENAA_P5));

  /* Enable RX addresses */
  nrf24_configRegister(EN_RXADDR,
                       (1<<ERX_P0)|(1<<ERX_P1)|(0<<ERX_P2)|(0<<ERX_P3)|(0<<ERX_P4)|(0<<ERX_P5));

  /* Auto retransmit delay: 1000 us and Up to 15 retransmit trials */
  nrf24_configRegister(SETUP_RETR,(0x04<<ARD)|(0x0F<<ARC));

  /* Dynamic length configurations: No dynamic length */
  nrf24_configRegister(DYNPD,
                       (0<<DPL_P0)|(0<<DPL_P1)|(0<<DPL_P2)|(0<<DPL_P3)|(0<<DPL_P4)|(0<<DPL_P5));

  /* Start listening */
  nrf24_powerUpRx();
}

/* Set the RX address */
void nrf24_rx_address(uint8_t* adr)
{
  nrf24_ce_digitalWrite(LOW);
  nrf24_writeRegister(RX_ADDR_P1,adr,nrf24_ADDR_LEN);
  nrf24_ce_digitalWrite(HIGH);
}

/* Returns the payload length */
uint8_t nrf24_payload_length(void)
{
  return payload_len;
}

/* Set the TX address */
void nrf24_tx_address(uint8_t* adr)
{
  /* RX_ADDR_P0 must be set to the sending addr for auto ack to work. */
  nrf24_writeRegister(RX_ADDR_P0,adr,nrf24_ADDR_LEN);
  nrf24_writeRegister(TX_ADDR,adr,nrf24_ADDR_LEN);
}

/* Checks if data is available for reading */
/* Returns 1 if data is ready ... */
uint8_t nrf24_dataReady(void)
{
  /* See note in getData(void) function - just checking RX_DR isn't good enough */
  uint8_t status = nrf24_getStatus();

  /* We can short circuit on RX_DR, but if it's not set, we still need */
  /* to check the FIFO for any pending packets */
  if ( status & (1 << RX_DR) ) {
    return 1;
  }

  return !nrf24_rxFifoEmpty();
}

/* Checks if receive FIFO is empty or not */
uint8_t nrf24_rxFifoEmpty(void)
{
  uint8_t fifoStatus;

  nrf24_readRegister(FIFO_STATUS,&fifoStatus,1);

  return (fifoStatus & (1 << RX_EMPTY));
}

/* Returns the length of data waiting in the RX fifo */
uint8_t nrf24_payloadLength(void)
{
  uint8_t status;
  nrf24_csn_digitalWrite(LOW);
  spi_transfer(R_RX_PL_WID);
  status = spi_transfer(0x00);
  nrf24_csn_digitalWrite(HIGH);
  return status;
}

/* Reads payload bytes into data array */
void nrf24_getData(uint8_t* data)
{
  /* Pull down chip select */
  nrf24_csn_digitalWrite(LOW);

  /* Send cmd to read rx payload */
  spi_transfer( R_RX_PAYLOAD );

  /* Read payload */
  nrf24_transferSync(data,data,payload_len);

  /* Pull up chip select */
  nrf24_csn_digitalWrite(HIGH);

  /* Reset status register */
  nrf24_configRegister(STATUS,(1<<RX_DR));
}

/* Returns the number of retransmissions occured for the last message */
uint8_t nrf24_retransmissionCount(void)
{
  uint8_t rv;
  nrf24_readRegister(OBSERVE_TX,&rv,1);
  rv = rv & 0x0F;
  return rv;
}

/* Sends a data package to the default address. Be sure to send the correct */
/* amount of bytes as configured as payload on the receiver. */
void nrf24_send(uint8_t* value)
{
  /* Go to Standby-I first */
  nrf24_ce_digitalWrite(LOW);

  /* Set to transmitter mode , Power up if needed */
  nrf24_powerUpTx();

  /* Do we really need to flush TX fifo each time ? */
  #if 1
  /* Pull down chip select */
  nrf24_csn_digitalWrite(LOW);

  /* Write cmd to flush transmit FIFO */
  spi_transfer(FLUSH_TX);

  /* Pull up chip select */
  nrf24_csn_digitalWrite(HIGH);
  #endif

  /* Pull down chip select */
  nrf24_csn_digitalWrite(LOW);

  /* Write cmd to write payload */
  spi_transfer(W_TX_PAYLOAD);

  /* Write payload */
  nrf24_transmitSync(value,payload_len);

  /* Pull up chip select */
  nrf24_csn_digitalWrite(HIGH);

  /* Start the transmission */
  nrf24_ce_digitalWrite(HIGH);
}

uint8_t nrf24_isSending(void)
{
  uint8_t status;

  /* read the current status */
  status = nrf24_getStatus();

  /* if sending successful (TX_DS) or max retries exceded (MAX_RT). */
  if((status & ((1 << TX_DS)  | (1 << MAX_RT)))) {
    return 0; /* false */
  }

  return 1; /* true */

}

uint8_t nrf24_getStatus(void)
{
  uint8_t rv;
  nrf24_csn_digitalWrite(LOW);
  rv = spi_transfer(NOP);
  nrf24_csn_digitalWrite(HIGH);
  return rv;
}

uint8_t nrf24_lastMessageStatus(void)
{
  uint8_t rv;

  rv = nrf24_getStatus();

  /* Transmission went OK */
  if((rv & ((1 << TX_DS)))) {
    return NRF24_TRANSMISSON_OK;
  }
  /* Maximum retransmission count is reached */
  /* Last message probably went missing ... */
  else if((rv & ((1 << MAX_RT)))) {
    return NRF24_MESSAGE_LOST;
  }
  /* Probably still sending ... */
  else {
    return 0xFF;
  }
}

void nrf24_powerUpRx(void)
{
  nrf24_csn_digitalWrite(LOW);
  spi_transfer(FLUSH_RX);
  nrf24_csn_digitalWrite(HIGH);

  nrf24_configRegister(STATUS,(1<<RX_DR)|(1<<TX_DS)|(1<<MAX_RT));

  nrf24_ce_digitalWrite(LOW);
  nrf24_configRegister(CONFIG,nrf24_CONFIG|((1<<PWR_UP)|(1<<PRIM_RX)));
  nrf24_ce_digitalWrite(HIGH);
}

void nrf24_powerUpTx(void)
{
  nrf24_configRegister(STATUS,(1<<RX_DR)|(1<<TX_DS)|(1<<MAX_RT));

  nrf24_configRegister(CONFIG,nrf24_CONFIG|((1<<PWR_UP)|(0<<PRIM_RX)));
}

void nrf24_powerDown(void)
{
  nrf24_ce_digitalWrite(LOW);
  nrf24_configRegister(CONFIG,nrf24_CONFIG);
}
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

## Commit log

2015-01-21 Added initial Arduino projects and Eagle & Gerber files for the LED matrix board.
    [ws2812b-board.brd, ws2812b-board.sch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]
2015-01-22 Screensaver is now actually drawn Turned really thick line into a square wave Fixed square wave size Fixed screensaver timeout button checks Fixed screen clear & game reset when leaving the screensav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
    [PixelShirtV2.ino]
2015-05-05 Removed double frame buffer (my 2D array & internal NeoPixel structure) Removed I2C code for GPU communication Added NeoPixel driver code Removed GPIO polling for controllers Added nRF wireless contr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
2015-05-09 Changed Pixel & nRF pins for prototyping Removed screen transposition Sped up heartbeat Initialized controller state & fixed button reading
    [radioPinFunctions.cpp]
2015-05-09 Moved LED_Board files into it's own folder
    [ws2812b-board.brd, ws2812b-board.sch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]
2015-05-09 Changed name from LED_Board to PixelShirtDisplay
    [ws2812b-board.brd, ws2812b-board.sch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]
2015-05-09 Added PixelShirtConsole EAGLE files
    [PixelShirtConsole.brd, PixelShirtConsole.sch]
2015-05-10 Moved some parts around for clearance Added logo, name Added Gerber files
    [PixelShirtConsole.brd, PixelShirtConsole.sch]
2015-05-12 Remade gerber files with EAGLE 6.6. Added dimension layer in .pls and .plc
2015-05-13 Fixed Y axis for new controller
2015-05-13 Fixed warnings for uninitialized variables
    [Pong.h]
2015-05-23 Modified pin definitions for new board Fixed schematic issue where the nRF had 5V powering it instead of 3.3V
    [PixelShirtConsole.brd, PixelShirtConsole.sch]
2015-05-30 Unrandomized tetromino colors with evenly spaced values around the color wheel
2015-12-24 Folded platform specific code into this project It can compile for both Arduino and as a terminal application Broke out score display code into it's own file
    [PlatformArduino.cpp]
2015-12-24 Added missing includes for Arduino build Renamed PixelShirtV2.cpp to PixelShirtV2.ino, for Arduino build Makefile still needs work Switched eclipse project type to makefile project
    [PixelShirtV2.ino, PlatformArduino.cpp, nrf24.cpp]
2015-12-24 Added PixelFighterGame Fixed keyboard analog input
    [PixelShirtV2.ino]
2015-12-25 Changed the way controller input is handled. Now it's done as the input arrives, rather than on the 32hz clock. This guarantees all input is processed. Updated documentation for PixelFighter Screensa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
    [PixelShirtV2.ino, PlatformArduino.cpp, Pong.h]
2015-12-25 Fixed perma-jump if the button is held A little more documentation
2016-01-10 Fixed Pong for new input scheme
    [Pong.h]
2016-01-10 Reverted NeoPixel code. The new code was bigger and wouldn't fit Tetris
    [PixelShirtV2.ino]
2016-01-10 Updated timer times for fighter
2016-01-10 Fixed input for Tetris for new input scheme Adjusted hit distance for PixelFighter Formatting
    [PixelShirtV2.ino, PlatformArduino.cpp]
2016-02-15 Don't allow movement when attacking or blocking Removed references to jumping When an attack is blocked, the next one is now faster Finalized timers
2016-03-05 Added BOMs
    [PixelShirt Console BOM.xls, PixelShirt Display BOM.xls]

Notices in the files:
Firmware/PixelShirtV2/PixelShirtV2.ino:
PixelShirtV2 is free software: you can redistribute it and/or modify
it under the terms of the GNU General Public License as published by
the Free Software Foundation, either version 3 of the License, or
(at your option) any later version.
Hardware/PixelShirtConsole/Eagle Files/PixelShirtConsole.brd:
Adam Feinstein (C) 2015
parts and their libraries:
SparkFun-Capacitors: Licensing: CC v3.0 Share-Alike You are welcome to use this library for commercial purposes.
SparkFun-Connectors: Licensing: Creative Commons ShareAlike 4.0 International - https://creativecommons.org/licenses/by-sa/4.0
